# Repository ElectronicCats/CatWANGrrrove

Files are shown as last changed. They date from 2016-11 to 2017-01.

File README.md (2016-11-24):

# LoRa Cat: Grrrove

Electronic Cats invests time and resources providing this open source design, please support Electronic Cats and open-source hardware by purchasing products from Electronic Cats!

Designed by Electronic Cats.

Firmware released under an GNU AGPL v3.0 license. See the LICENSE file for more information.

Hardware released under an CERN Open Hardware Licence v1.2. See the LICENSE_HARDWARE file for more information.

Electronic Cats is a registered trademark, please do not use if you sell these PCBs.

23 Nov 2016

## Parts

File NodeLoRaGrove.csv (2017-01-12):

Reference | Value | Footprint | Datasheet | Description | MF | Price | MP | Availability | manf#
MODULE1 | RN2903 | TIH:RN2483 | None | Sub-GHz Dual Band Long Range Transceiver LoRa Module | Microchip | 14.12 USD | RN2483-I/RM095 | Bad | RN2903-I/RM095
U1 | AP2112 | TO_SOT_Packages_SMD:SOT-23-5 |  |  |  |  |  |  | AP2112K-3.3TRG1
P3 | USB_A | TIH:10118192-0001LF |  |  |  |  |  |  | 105017-0001
P7 | I2C | Connectors_JST:JST_PH_S4B-PH-K_04x2.00mm_Angled
Y1 | 8Mhz | Crystals:Crystal_HC49-SD_SMD |  |  |  |  |  |  | HC49SSDLF-8.00MHz
C8 | 22pF | Capacitors_SMD:C_0805_HandSoldering |  |  |  |  |  |  | 885012007012
C9 | 22pF | Capacitors_SMD:C_0805_HandSoldering |  |  |  |  |  |  | 885012007012
C7 | 1uF | Capacitors_SMD:C_0805_HandSoldering |  |  |  |  |  |  | GRM21BR71C105KA01L
R9 | 22R | Resistors_SMD:R_0805_HandSoldering |  |  |  |  |  |  | BLM21PG220SN1D
R10 | 22R | Resistors_SMD:R_0805_HandSoldering |  |  |  |  |  |  | BLM21PG220SN1D
R2 | 100K | Resistors_SMD:R_0805_HandSoldering |  |  |  |  |  |  | WR08X1003FTL
C1 | 10uF | Capacitors_SMD:C_0805_HandSoldering |  |  |  |  |  |  | GRM21BR61A106KE19L
C2 | 10uF | Capacitors_SMD:C_0805_HandSoldering |  |  |  |  |  |  | GRM21BR61A106KE19L
D1 | MBR120 | Diodes_SMD:SOD-123 |  |  |  |  |  |  | NRVB120VLSFT1G
R8 | 10K | Resistors_SMD:R_0805_HandSoldering |  |  |  |  |  |  | CPF0805B10KE1
U2 | MCP73831T-2ATI/OT | TO_SOT_Packages_SMD:SOT-23-5 | SOT-23 Microchip | MCP73831 Series Li-Ion/Li-Pol 15 mA - 500 mA 4.2 V Charge Controller - SOT-23-5 | Microchip | 0.48 USD | MCP73831T-2ATI/OT | Good | MCP73831T-2DCI/OT
R4 | 330R | Resistors_SMD:R_0805_HandSoldering |  |  |  |  |  |  | ESR10EZPF3300
D3 | CHG | LEDs:LED_0805 |  |  |  |  |  |  | LTST-C170KRKT
P4 | Battery | Pin_Headers:Pin_Header_Straight_1x02
D4 | DONE | LEDs:LED_0805 |  |  |  |  |  |  | SM0805GCL
R5 | 330R | Resistors_SMD:R_0805_HandSoldering |  |  |  |  |  |  | ESR10EZPF3300
C6 | 10uF | Capacitors_SMD:C_0805_HandSoldering |  |  |  |  |  |  | GRM21BR61A106KE19L
R12 | 4.7K | Resistors_SMD:R_0805_HandSoldering |  |  |  |  |  |  | RG2012P-472-B-T5
R11 | 4.7K | Resistors_SMD:R_0805_HandSoldering |  |  |  |  |  |  | RG2012P-472-B-T5
SW1 | SW_PUSH | TIH:SW_SPST_KMR2 |  |  |  |  |  |  | KMR211G LFS
R7 | 10K | Resistors_SMD:R_0805_HandSoldering |  |  |  |  |  |  | CPF0805B10KE1
P1 | PICKIT PROGRAMMER | Pin_Headers:Pin_Header_Straight_1x05
R3 | 10K | Resistors_SMD:R_0805_HandSoldering |  |  |  |  |  |  | CPF0805B10KE1
P8 | A2 | Connectors_JST:JST_PH_S4B-PH-K_04x2.00mm_Angled
P5 | A0 | Connectors_JST:JST_PH_S4B-PH-K_04x2.00mm_Angled
P6 | D9 | Connectors_JST:JST_PH_S4B-PH-K_04x2.00mm_Angled
C4 | 0.1uF | Capacitors_SMD:C_0805_HandSoldering |  |  |  |  |  |  | GRM21BR71E104KA01L
R1 | 100R | Resistors_SMD:R_0805_HandSoldering |  |  |  |  |  |  | ESR10EZPJ101
D2 | Led | LEDs:LED_0805 |  |  |  |  |  |  | LTST-C170TBKT
C5 | 0.1uF | Capacitors_SMD:C_0805_HandSoldering |  |  |  |  |  |  | GRM21BR71E104KA01L
A1 | ANT | TIH:GSG-SMA-EDGE |  |  |  |  |  |  | CONSMA003.062
C3 | 1uF | Capacitors_SMD:C_0805_HandSoldering |  |  |  |  |  |  | GRM21BR71C105KA01L
D5 | LED | LEDs:LED_0805 |  |  |  |  |  |  | LTST-C170TBKT
R6 | 330 | Resistors_SMD:R_0805_HandSoldering |  |  |  |  |  |  | ESR10EZPF3300
U3 | ATmega32U4-AU | Housings_QFP:TQFP-44_10x10mm_Pitch0.8mm |  |  |  |  |  |  | ATMEGA32U2-AU
P2 | ICSP | Pin_Headers:Pin_Header_Straight_2x03

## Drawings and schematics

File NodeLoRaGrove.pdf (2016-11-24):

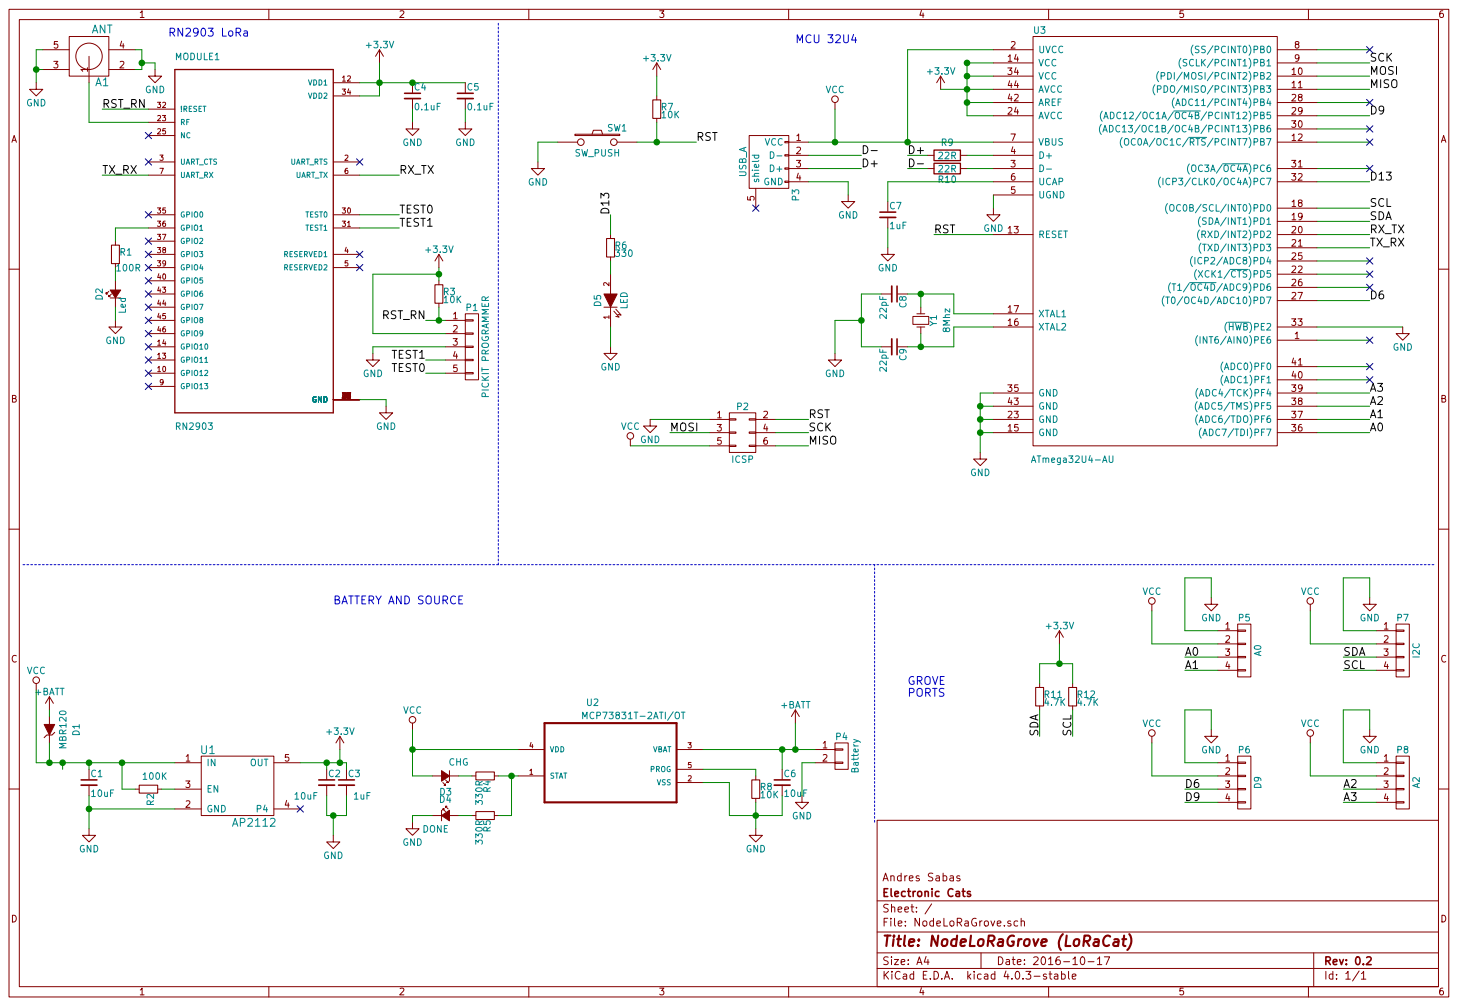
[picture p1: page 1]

Id: 1/1 Title: NodeLoRaGrove (LoRaCat) File: NodeLoRaGrove.sch Sheet: / Electronic Cats Andres Sabas

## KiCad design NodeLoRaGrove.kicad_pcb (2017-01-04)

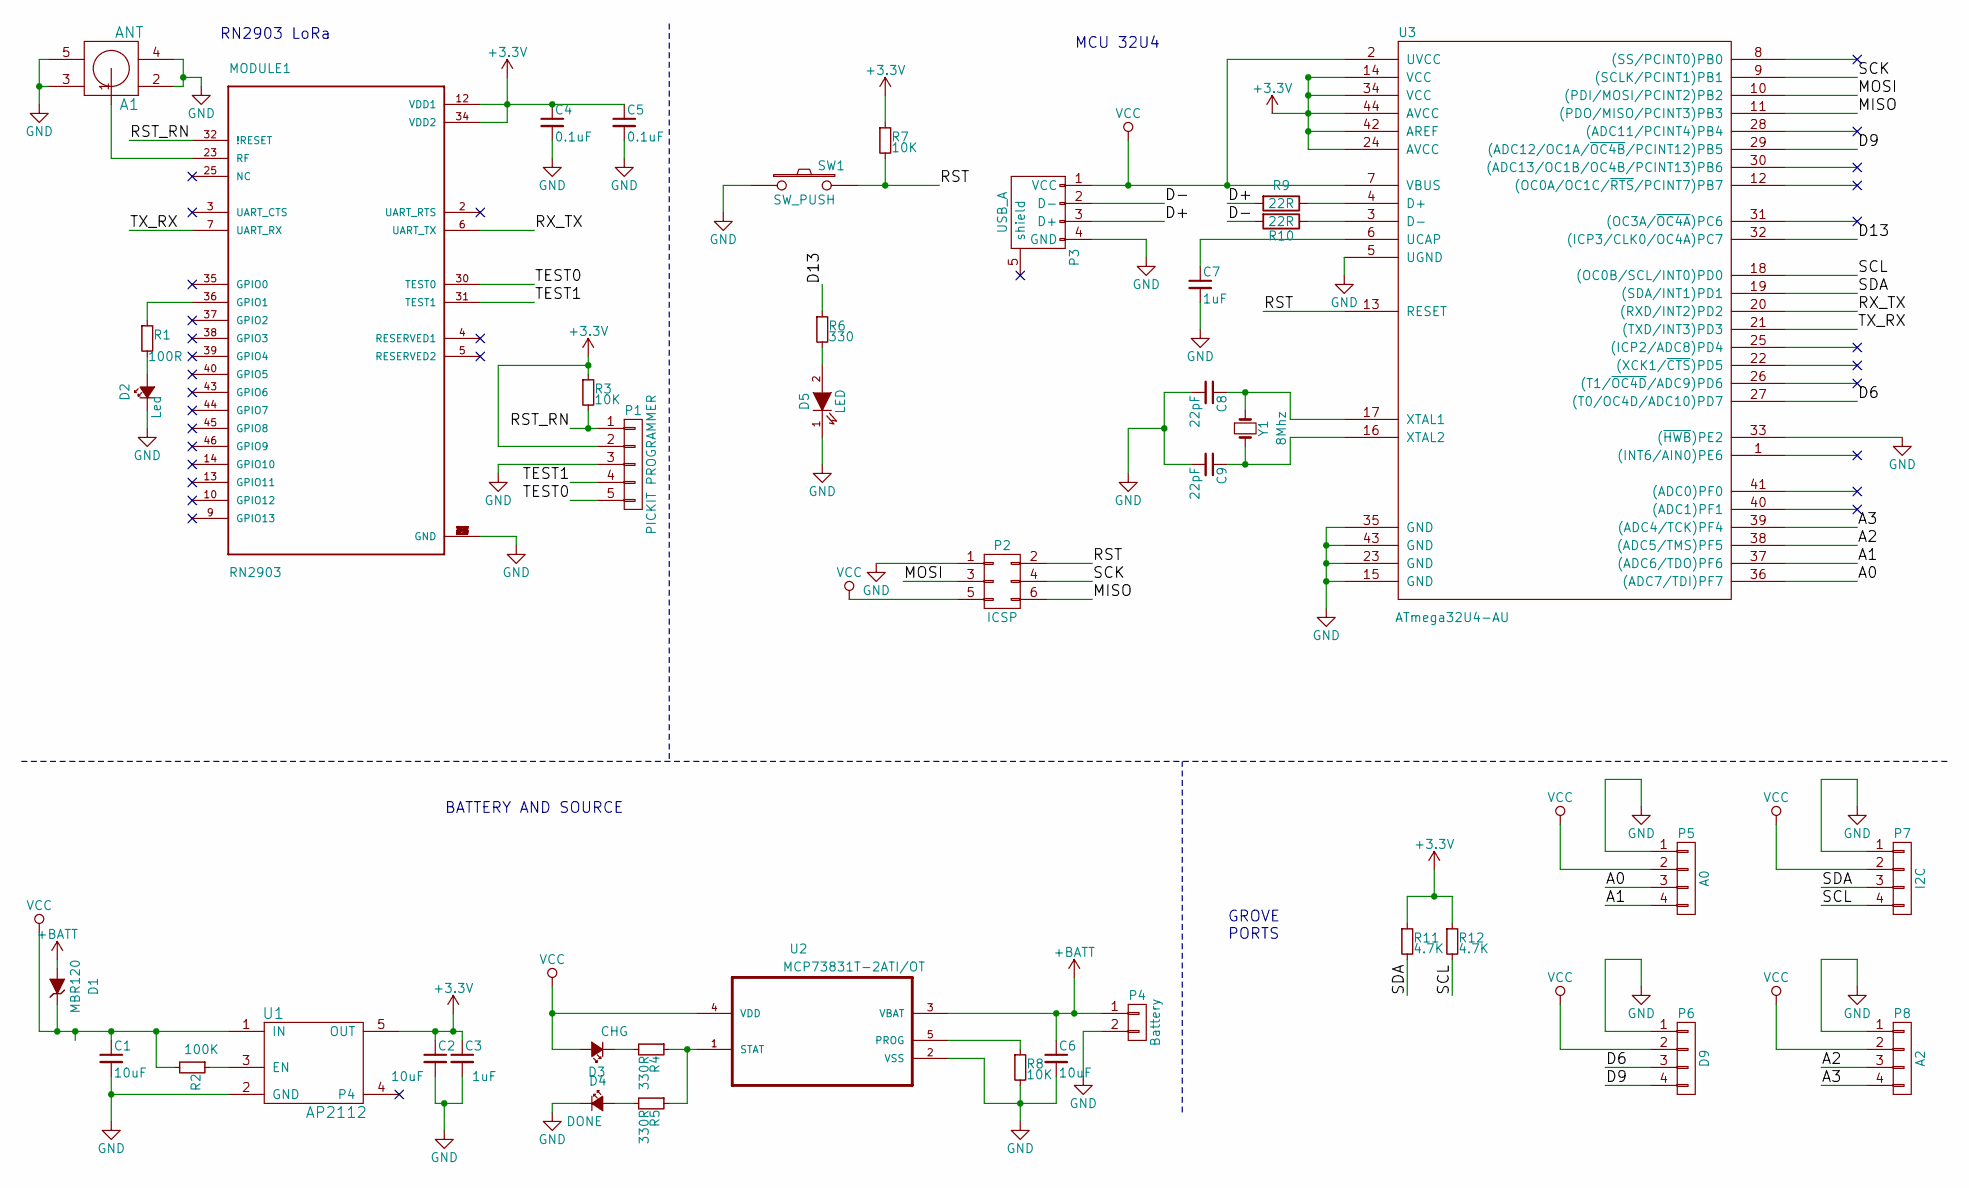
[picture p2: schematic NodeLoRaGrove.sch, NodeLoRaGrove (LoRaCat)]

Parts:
A1: ANT; GSG-SMA-EDGE
C1, C2, C6: 10uF; C_0805_HandSoldering
C3, C7: 1uF; C_0805_HandSoldering
C4, C5: 0.1uF; C_0805_HandSoldering
C8, C9: 22pF; C_0805_HandSoldering
D1: MBR120; SOD-123
D2: Led; LED_0805
D3: CHG; LED_0805
D4: DONE; LED_0805
D5: LED; LED_0805
MODULE1: RN2903; RN2483
P1: PICKIT PROGRAMMER; Pin_Header_Straight_1x05
P2: ICSP; Pin_Header_Straight_2x03
P3: USB_A; 10118192-0001LF
P4: Battery; Pin_Header_Straight_1x02
P5: A0; JST_PH_S4B-PH-K_04x2.00mm_Angled
P6: D9; JST_PH_S4B-PH-K_04x2.00mm_Angled
P7: I2C; JST_PH_S4B-PH-K_04x2.00mm_Angled
P8: A2; JST_PH_S4B-PH-K_04x2.00mm_Angled
R1: 100R; R_0805_HandSoldering
R2: 100K; R_0805_HandSoldering
R3, R7, R8: 10K; R_0805_HandSoldering
R4, R5: 330R; R_0805_HandSoldering
R6: 330; R_0805_HandSoldering
R9, R10: 22R; R_0805_HandSoldering
R11, R12: 4.7K; R_0805_HandSoldering
SW1: SW_PUSH; SW_SPST_KMR2
U1: AP2112; SOT-23-5
U2: MCP73831T-2ATI/OT; SOT-23-5
U3: ATmega32U4-AU; TQFP-44_10x10mm_Pitch0.8mm
Y1: 8Mhz; Crystal_HC49-SD_SMD

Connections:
+3V3: C2.1, C3.1, C4.1, C5.1, MODULE1.12 (VDD1), MODULE1.34 (VDD2), P1.2, R3.1, R7.1, R11.1, R12.1, U1.5 (OUT), U3.14 (VCC), U3.24 (AVCC), U3.34 (VCC), U3.42 (AREF), U3.44 (AVCC); also elsewhere on the board
+BATT: C6.1, D1.2 (A), P4.1, U2.3 (VBAT)
/A0: P5.3, U3.36 ((ADC7/TDI)PF7)
/A1: P5.4, U3.37 ((ADC6/TDO)PF6)
/A2: P8.3, U3.38 ((ADC5/TMS)PF5)
/A3: P8.4, U3.39 ((ADC4/TCK)PF4)
/D6: P6.3, U3.27 ((T0/OC4D/ADC10)PD7)
/D9: P6.4, U3.29 ((ADC12/OC1A/~OC4B~/PCINT12)PB5)
/D13: R6.1, U3.32 ((ICP3/CLK0/OC4A)PC7)
/D+: P3.3 (D+), R9.2
/D-: P3.2 (D-), R10.2
/MISO: P2.6, U3.11 ((PDO/MISO/PCINT3)PB3)
/MOSI: P2.3, U3.10 ((PDI/MOSI/PCINT2)PB2)
/RST: P2.2, R7.2, SW1.2, U3.13 (RESET)
/RST_RN: MODULE1.32 (!RESET), P1.1, R3.2; also elsewhere on the board
/RX_TX: MODULE1.6 (UART_TX), U3.20 ((RXD/INT2)PD2); also elsewhere on the board
/SCK: P2.4, U3.9 ((SCLK/PCINT1)PB1)
/SCL: P7.4, R12.2, U3.18 ((OC0B/SCL/INT0)PD0)
/SDA: P7.3, R11.2, U3.19 ((SDA/INT1)PD1)
/TEST0: MODULE1.30 (TEST0), P1.5; also elsewhere on the board
/TEST1: MODULE1.31 (TEST1), P1.4; also elsewhere on the board
/TX_RX: MODULE1.7 (UART_RX), U3.21 ((TXD/INT3)PD3); also elsewhere on the board
GND: A1.2, A1.3, A1.4, A1.5, C1.2, C2.2, C3.2, C4.2, C5.2, C6.2, C7.2, C8.2, C9.2, D2.1 (K), D4.1 (K), D5.1 (K), MODULE1.1 (GND), MODULE1.8 (GND), MODULE1.11 (GND), MODULE1.20 (GND), MODULE1.21 (GND), MODULE1.22 (GND), MODULE1.24 (GND), MODULE1.26 (GND), MODULE1.27 (GND), MODULE1.28 (GND), MODULE1.33 (GND), MODULE1.41 (GND), MODULE1.47 (GND), P1.3, P2.1, P3.4 (GND), P4.2, P5.1, P6.1, P7.1, P8.1, R8.2, SW1.1, U1.2 (GND), U2.2 (VSS), U3.5 (UGND), U3.15 (GND), U3.23 (GND), U3.33 ((~HWB~)PE2), U3.35 (GND), U3.43 (GND); also elsewhere on the board
unnamed 23: A1.1, MODULE1.23 (RF); also elsewhere on the board
unnamed: C7.1, U3.6 (UCAP)
unnamed: C8.1, U3.17 (XTAL1), Y1.1
unnamed: C9.1, U3.16 (XTAL2), Y1.2
unnamed: D2.2 (A), R1.2
unnamed: D3.1 (K), R4.2
unnamed: D4.2 (A), R5.2
unnamed: D5.2 (A), R6.2
unnamed 41: MODULE1.36 (GPIO1), R1.1; also elsewhere on the board
unnamed: R2.1, U1.3 (EN)
unnamed: R4.1, R5.1, U2.1 (STAT)
unnamed: R8.1, U2.5 (PROG)
unnamed: R9.1, U3.4 (D+)
unnamed: R10.1, U3.3 (D-)
VCC: C1.1, D1.1 (K), D3.2 (A), P2.5, P3.1 (VCC), P5.2, P6.2, P7.2, P8.2, R2.2, U1.1 (IN), U2.4 (VDD), U3.2 (UVCC), U3.7 (VBUS)

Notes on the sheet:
RN2903 LoRa
MCU 32U4
GROVE PORTS
BATTERY AND SOURCE

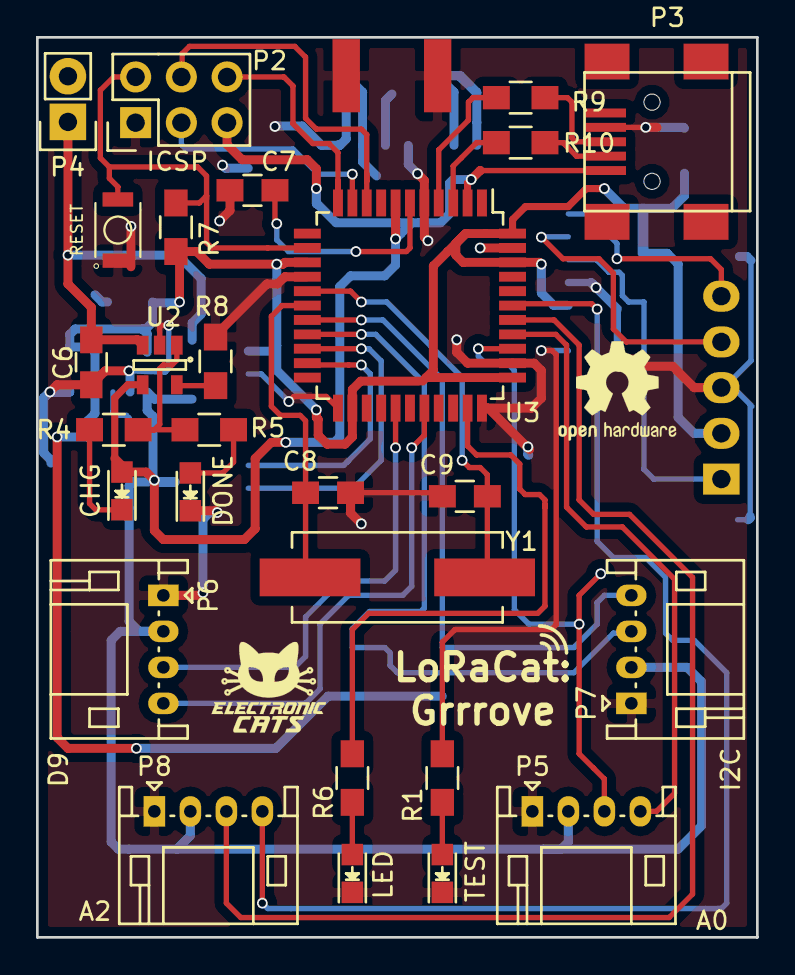
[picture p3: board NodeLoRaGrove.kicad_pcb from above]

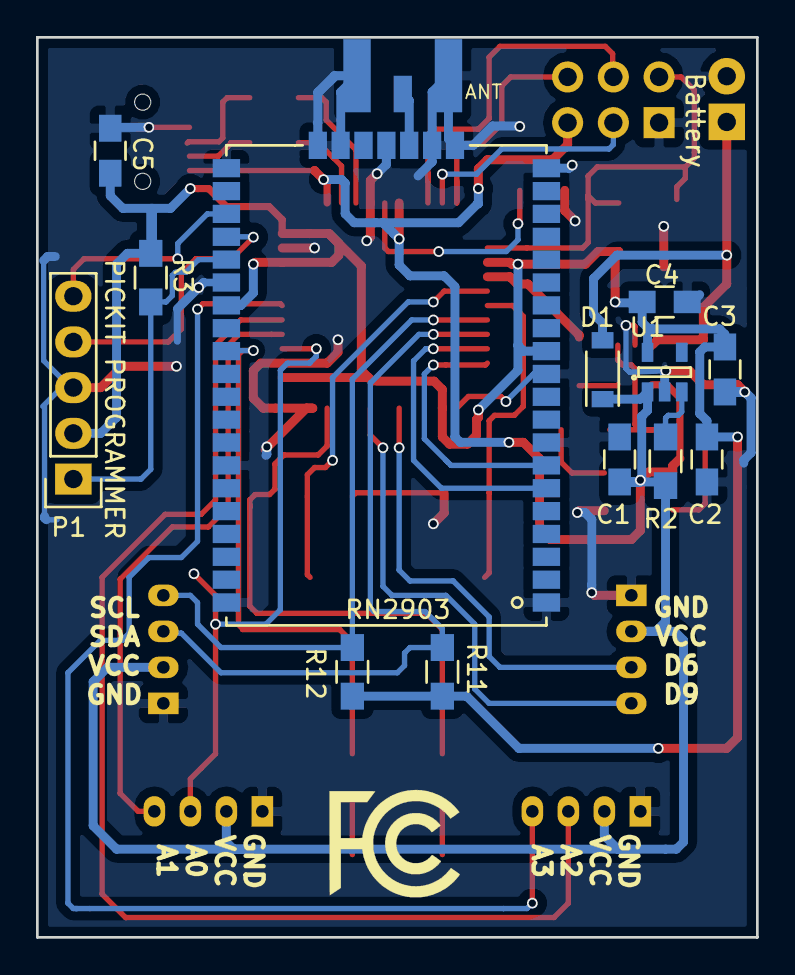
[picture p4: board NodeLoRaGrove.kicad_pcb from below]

Board: 2 copper layers, 40.0 x 50.0 mm, 41 parts (14 on the bottom side), 38 nets.

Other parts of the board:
RN2903: RN2903; RN2483

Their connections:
+3V3: RN2903.12, RN2903.34; also elsewhere on the board
/RST_RN: RN2903.32; also elsewhere on the board
/RX_TX: RN2903.6; also elsewhere on the board
/TEST0: RN2903.30; also elsewhere on the board
/TEST1: RN2903.31; also elsewhere on the board
/TX_RX: RN2903.7; also elsewhere on the board
GND: RN2903.1, RN2903.8, RN2903.11, RN2903.20, RN2903.21, RN2903.22, RN2903.24, RN2903.26, RN2903.27, RN2903.28, RN2903.33, RN2903.41, RN2903.47; also elsewhere on the board
unnamed 23: RN2903.23; also elsewhere on the board
unnamed 41: RN2903.36; also elsewhere on the board

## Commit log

2016-09-10 Schematic v0.1b
    [NodeLoRaGrove.kicad_pcb, NodeLoRaGrove.sch]
2016-09-30 Update footprint and lib
2016-09-30 Update schematic
    [NodeLoRaGrove.sch]
2016-09-30 Init PCB
    [NodeLoRaGrove.kicad_pcb, NodeLoRaGrove.sch]
2016-10-02 Add PCB 0.8v
    [NodeLoRaGrove.kicad_pcb]
2016-10-03 Update labels and added logo ElectronicCats
    [NodeLoRaGrove.kicad_pcb, NodeLoRaGrove.sch]
2016-10-18 Update Schematic remove leds
    Notes and leds remove
    [NodeLoRaGrove.kicad_pcb, NodeLoRaGrove.sch]
2016-12-06 Added PCB 0.9v
    [NodeLoRaGrove.kicad_pcb]
2016-12-06 Added logos and change button
    [NodeLoRaGrove.kicad_pcb]
2016-12-06 Check DRC PCB
    [NodeLoRaGrove.kicad_pcb]
2016-12-15 Change USB connector
    [NodeLoRaGrove.kicad_pcb, NodeLoRaGrove.sch]
2017-01-03 Update logos
    [NodeLoRaGrove.kicad_pcb]
2017-01-04 Some vias and tracks fix
    [NodeLoRaGrove.kicad_pcb]
2017-01-04 Add ondas mamalonas
    [NodeLoRaGrove.kicad_pcb]
2017-01-04 Changed USB
    [NodeLoRaGrove.kicad_pcb]
2017-01-04 Fix Skilcreen
    [NodeLoRaGrove.kicad_pcb, NodeLoRaGrove.sch]
2017-01-12 added bom
    [NodeLoRaGrove.sch]
2017-01-12 change gitignore ass csv
    [NodeLoRaGrove.csv]
